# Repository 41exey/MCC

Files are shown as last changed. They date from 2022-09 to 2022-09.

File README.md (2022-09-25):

# Microclimate controller (MCC)







> Project based STM32F030K6T6

## Dependensies

- CMSIS

## Uses hardware

- TIM1 - sensor
- TIM3_CH3 PWM - backlight
- TIM14 - buttons
- TIM16 - time
- TIM17 - empty

- ADC1_IRQ - battery level

- Internal flash - storage settings

## Clone

> Clone this repo to your local machine using `git clone https://github.com/c1ewd/MCC`

## Features

> Device intended for measuring humidity and temperature. By deviation from specified range of temperature or humidity it send sound signal.
> Hardware design was making in Eagle CAD. Software was coding in IAR.
> Device is using digital humidity and temperature sensor AM2302. For sound signal using EFM-475. For graphical interface using Nokia 5110 display.

## Donations (Optional)

Liberapay (https://liberapay.com/c1ewd/donate)

## License

- **[Apache 2.0 license](http://www.apache.org/licenses/LICENSE-2.0)**
- Copyright © 2020 <a href="https://teleg.run/c1ewd" target="_blank">c1ewd</a>.

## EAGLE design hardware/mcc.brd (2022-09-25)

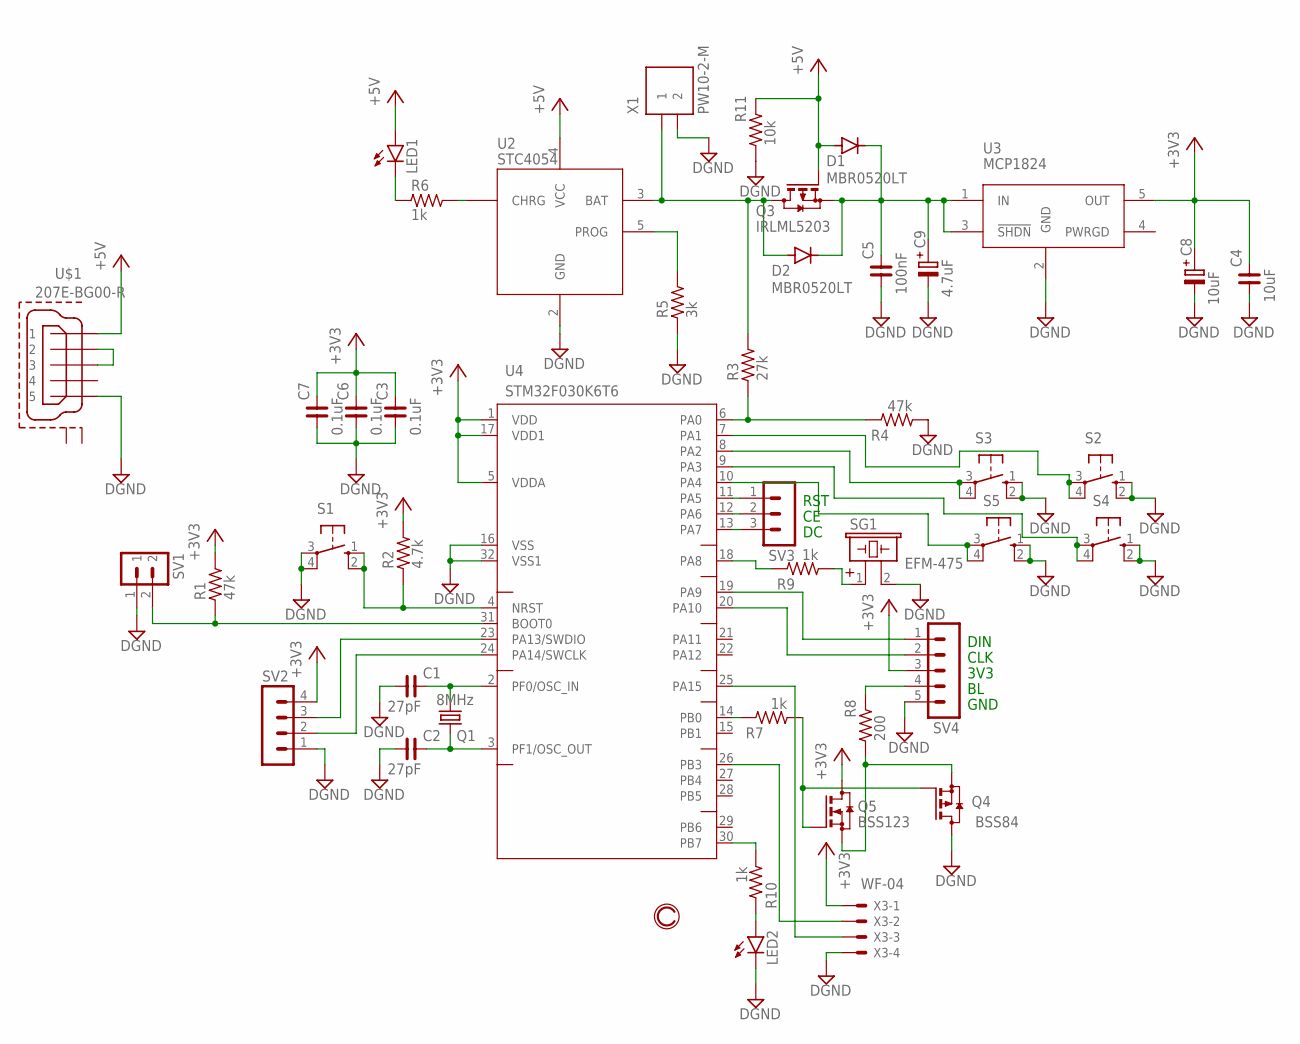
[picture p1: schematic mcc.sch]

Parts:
C1, C2: 27pF; C0805
C3, C6, C7: 0.1uF; C0805
C4: 10uF; C1206
C5: 100nF; C0805
C8: 10uF; SV-C
C9: 4.7uF; SV-C
D1, D2: MBR0520LT; SOD123
LED1, LED2: LEDSML0805; SML0805
Q1: 8MHz; HC49UP
Q3: IRLML5203; SOT23
Q4: BSS84; SOT23
Q5: BSS123; SOT23
R1, R4: 47k; R0805
R2: 4.7k; R0805
R3: 27k; R0805
R5: 3k; R0805
R6, R7, R9, R10: 1k; R0805
R8: 200; R0805
R11: 10k; R0805
S1, S2, S3, S4, S5: 10-XX; B3F-10XX
SG1: EFM-475; EFM-472
SV1: MA02-1
SV2: MA04-1
SV3: MA03-1
SV4: MA05-1
U2: STC4054; SOT23-5L
U3: MCP1824; SOT23-5L
U4: STM32F030K6T6; LQFP-32
U$1: 207E-BG00-R
X1: PW10-2-M; MKS1852-6-0-202
X3: WF-04; 22-23-2041

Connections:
+3V3: C3.2, C4.2, C6.2, C7.2, C8.+, Q5.3 (D), R1.2, R2.2, SV2.4, SV4.3, U3.5 (OUT), U4.1 (VDD), U4.5 (VDDA), U4.17 (VDD1), X3.1
BAT: D2.A, Q3.3 (D), R3.2, U2.3 (BAT), X1.1
BL: R7.2, U4.14 (PB0)
BOOT0: R1.1, SV1.2, U4.31 (BOOT0)
BUZZER: R9.2, U4.18 (PA8)
CE: SV3.2, U4.12 (PA6)
CHRG: R6.2, U2.1 (CHRG)
CLK: SV4.2, U4.20 (PA10)
DATA: U4.26 (PB3), X3.2
DC: SV3.3, U4.13 (PA7)
DGND: C1.1, C2.1, C3.1, C4.1, C5.1, C6.1, C7.1, C8.-, C9.-, LED2.C, Q4.3 (D), R4.1, R5.1, R11.1, S1.3, S1.4 (P1), S2.1 (S), S2.2 (S1), S3.1 (S), S3.2 (S1), S4.1 (S), S4.2 (S1), S5.1 (S), S5.2 (S1), SG1.2, SV1.1, SV2.1, SV4.5, U2.2 (GND), U3.2 (GND), U4.16 (VSS), U4.32 (VSS1), U$1.P$5 (5), X1.2, X3.4
DIN: SV4.1, U4.19 (PA9)
DIV_BAT: R3.1, R4.2, U4.6 (PA0)
LED2: R10.1, U4.30 (PB7)
unnamed: C5.2, C9.+, D1.C, D2.C, Q3.2 (S), U3.1 (IN), U3.3 (!SHDN)
unnamed: U$1.P$2 (2), U$1.P$3 (3)
unnamed: R8.2, SV4.4
unnamed: U4.25 (PA15), X3.3
NRST: R2.1, S1.1 (S), S1.2 (S1), U4.4 (NRST)
PF0-OSC_IN: C1.2, Q1.1, U4.2 (PF0/OSC_IN)
PF1-OSC_OUT: C2.2, Q1.2, U4.3 (PF1/OSC_OUT)
PROG: R5.2, U2.5 (PROG)
RST: SV3.1, U4.11 (PA5)
R_BL: Q4.1 (G), Q5.1 (G), R7.1
R_BUZZER: R9.1, SG1.1
R_CHRG: LED1.C, R6.1
R_LED2: LED2.A, R10.2
S2: S2.3, S2.4 (P1), U4.7 (PA1)
S3: S3.3, S3.4 (P1), U4.8 (PA2)
S4: S4.3, S4.4 (P1), U4.9 (PA3)
S5: S5.3, S5.4 (P1), U4.10 (PA4)
SWCLK: SV2.2, U4.24 (PA14/SWCLK)
SWDIO: SV2.3, U4.23 (PA13/SWDIO)
VCC: D1.A, LED1.A, Q3.1 (G), R11.2, U2.4 (VCC), U$1.P$1 (1)
Е_BL: Q4.2 (S), Q5.2 (S), R8.1

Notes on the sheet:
RST
DIN
CLK
3V3
GND

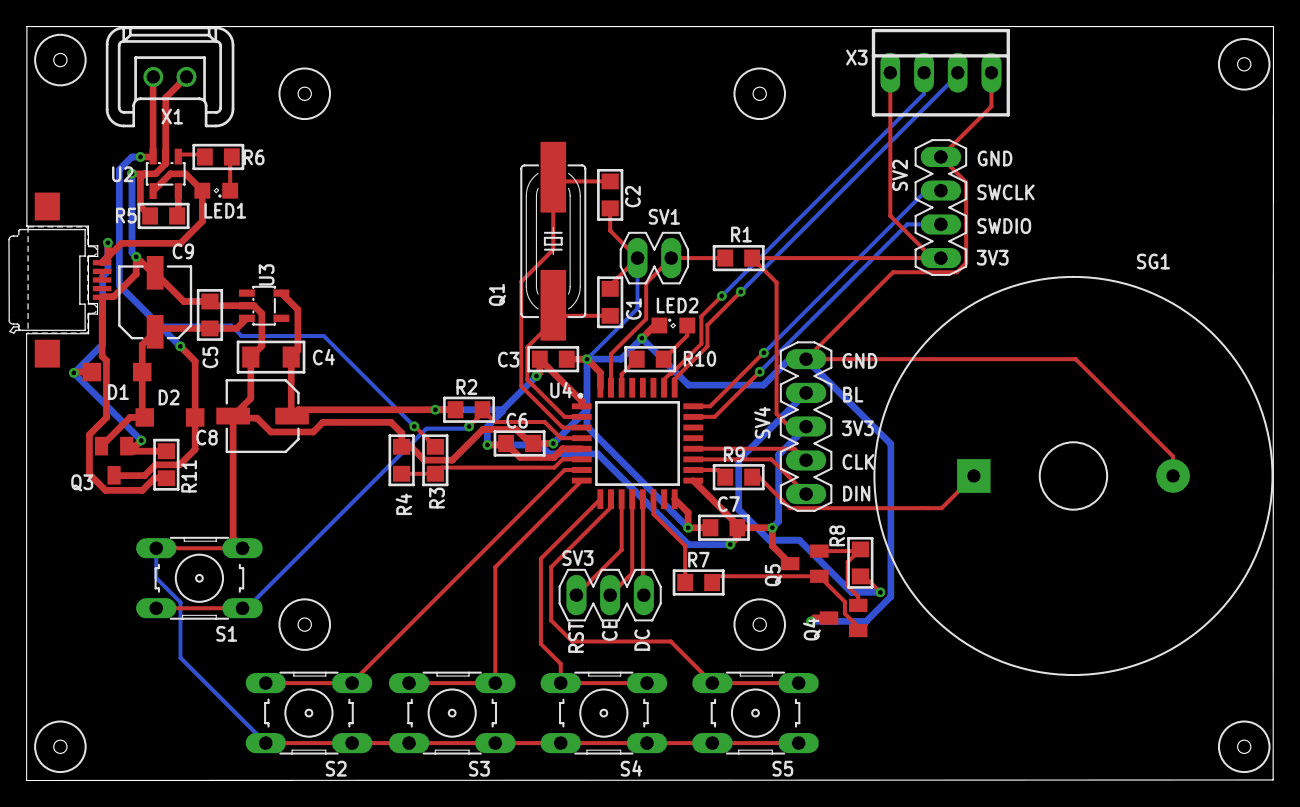
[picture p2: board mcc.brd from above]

Board: 2 copper layers, 94.0 x 56.8 mm, 44 parts (0 on the bottom side), 35 nets.

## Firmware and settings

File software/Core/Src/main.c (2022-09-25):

/*
 * Copyright 2020 c1ewd
 *
 * Licensed under the Apache License, Version 2.0 (the "License");
 * you may not use this file except in compliance with the License.
 * You may obtain a copy of the License at
 *
 *      http://www.apache.org/licenses/LICENSE-2.0
 *
 * Unless required by applicable law or agreed to in writing, software
 * distributed under the License is distributed on an "AS IS" BASIS,
 * WITHOUT WARRANTIES OR CONDITIONS OF ANY KIND, either express or implied.
 * See the License for the specific language governing permissions and
 * limitations under the License.
 */

#include "main.h"
#include "define.h"

#include "am2302.h"
#include "buttons.h"
#include "backlight.h"
#include "flash.h"
#include "string.h"
#include "sound.h"

/**
Test function indicates that MCU works
*/
void TIM17_IRQHandler(void)
{
//  LED_PORT->ODR ^= LED_ODR;
//  BUZZER_PORT->ODR ^= BUZZER_ODR;
    
  TIM17->SR &=~ TIM_SR_UIF;
}

/**
 * Program delay in milliseconds
 * @param ms delay in milliseconds
 */
void delay(uint32_t ms) {
  for(int i = 0; i < ms; i ++)
  {//48000000
    for(int j = 0; j < 48000; j ++)
    {
      __NOP();
    }
  }
}

int main(void)
{

  RCC->AHBENR |= RCC_AHBENR_GPIOBEN;
  // led
  GPIOB->MODER |= GPIO_MODER_MODER7_0;
  GPIOB->OTYPER &= ~GPIO_OTYPER_OT_7;
  GPIOB->OSPEEDR |= GPIO_OSPEEDER_OSPEEDR7;
  GPIOB->PUPDR |= GPIO_PUPDR_PUPDR7_0;
  
  RCC->AHBENR |= RCC_AHBENR_GPIOAEN;
  // Display
  // PA5
  GPIOA->MODER |= GPIO_MODER_MODER5_0;
  GPIOA->OTYPER &= ~GPIO_OTYPER_OT_5;
  GPIOA->OSPEEDR |= GPIO_OSPEEDER_OSPEEDR5;
  GPIOA->PUPDR &= ~GPIO_PUPDR_PUPDR5;
  // PA6
  GPIOA->MODER |= GPIO_MODER_MODER6_0;
  GPIOA->OTYPER &= ~GPIO_OTYPER_OT_6;
  GPIOA->OSPEEDR |= GPIO_OSPEEDER_OSPEEDR6;
  GPIOA->PUPDR &= ~GPIO_PUPDR_PUPDR6;   
  // PA7
  GPIOA->MODER |= GPIO_MODER_MODER7_0;
  GPIOA->OTYPER &= ~GPIO_OTYPER_OT_7;
  GPIOA->OSPEEDR |= GPIO_OSPEEDER_OSPEEDR7;
  GPIOA->PUPDR &= ~GPIO_PUPDR_PUPDR7;     
  // PA9
  GPIOA->MODER |= GPIO_MODER_MODER9_0;
  GPIOA->OTYPER &= ~GPIO_OTYPER_OT_9;
  GPIOA->OSPEEDR |= GPIO_OSPEEDER_OSPEEDR9;
  GPIOA->PUPDR &= ~GPIO_PUPDR_PUPDR9;
  // PA10
  GPIOA->MODER |= GPIO_MODER_MODER10_0;
  GPIOA->OTYPER &= ~GPIO_OTYPER_OT_10;
  GPIOA->OSPEEDR |= GPIO_OSPEEDER_OSPEEDR10;
  GPIOA->PUPDR &= ~GPIO_PUPDR_PUPDR10; 

  // PWM Display
  // TIM3_CH3
  // Configure PB0 for BL of LCD
//  GPIOB->MODER &= ~GPIO_MODER_MODER0;
  GPIOB->MODER |= GPIO_MODER_MODER0_1;
  GPIOB->OTYPER &= ~GPIO_OTYPER_OT_0;
  GPIOB->OSPEEDR |= GPIO_OSPEEDER_OSPEEDR0;
  GPIOB->PUPDR &= ~GPIO_PUPDR_PUPDR0;    
    
  // Enable PWM for LCD
  // Select AF1 on PB0 in AFRL for TIM3_CH3
  GPIOB->AFR[0] |= 0x01 << GPIO_AFRL_AFRL0_Pos;
  RCC->APB1ENR |= RCC_APB1ENR_TIM3EN;
  TIM3->PSC = 4800 - 1;
  TIM3->ARR = 100;
  TIM3->CCR3 = 100;
  TIM3->CCER |= TIM_CCER_CC3E;
  TIM3->BDTR |= TIM_BDTR_MOE;
  TIM3->CCMR2 = TIM_CCMR2_OC3M_2 | TIM_CCMR2_OC3M_1 | TIM_CCMR2_OC3PE;
  NVIC_SetPriority(TIM3_IRQn, 1);
  NVIC_EnableIRQ(TIM3_IRQn);
  TIM3->DIER = TIM_DIER_UIE;    
  TIM3->EGR |= TIM_EGR_UG;
    
  // time
  RCC->APB2ENR |= RCC_APB2ENR_TIM16EN;
  TIM16->PSC = 48000 - 1;
  TIM16->ARR = 500 - 1; // one per second, tested
  TIM16->CNT = 0;
  NVIC_SetPriority(TIM16_IRQn, 1);
  NVIC_EnableIRQ(TIM16_IRQn);
  TIM16->DIER = TIM_DIER_UIE;    
  TIM16->CR1 |= TIM_CR1_CEN | TIM_CR1_ARPE;
  
  // buzzer
  GPIOA->MODER |= GPIO_MODER_MODER8_0;
  GPIOA->OTYPER &= ~GPIO_OTYPER_OT_8;
  GPIOA->OSPEEDR |= GPIO_OSPEEDER_OSPEEDR8;
  GPIOA->PUPDR &= ~GPIO_PUPDR_PUPDR8;
  
  // TIM for tests
  /*
  RCC->APB2ENR |= RCC_APB2ENR_TIM17EN;
  TIM17->PSC = 48000 - 1;
  TIM17->ARR = 500;
  TIM17->CNT = 0;
  NVIC_SetPriority(TIM17_IRQn, 1);
  NVIC_EnableIRQ(TIM17_IRQn);
  TIM17->DIER = TIM_DIER_UIE;    
  TIM17->CR1 |= TIM_CR1_CEN | TIM_CR1_ARPE;
*/
  
  // PA0 ADC
  GPIOA->MODER |= GPIO_MODER_MODER0;
  // RCC of ADC
  RCC->APB2ENR |= RCC_APB2ENR_ADC1EN;
  RCC->CR2 |= RCC_CR2_HSI14ON;
  while((RCC->CR2 & RCC_CR2_HSI14RDY) == 0) {

  }

  ADC1->CFGR2 &= ~ADC_CFGR2_CKMODE;
  ADC1->CFGR2 |= ADC_CFGR2_CKMODE_1;
    
  ADC1->CFGR1 = 0;
    
  ADC1->CFGR1 |= ADC_CFGR1_CONT | ADC_CFGR1_SCANDIR;
  ADC1->CHSELR = ADC_CHSELR_CHSEL0;
  ADC1->SMPR |= ADC_SMPR_SMP_0 | ADC_SMPR_SMP_1 | ADC_SMPR_SMP_2;
  ADC1->IER = ADC_IER_EOCIE;
  NVIC_EnableIRQ(ADC1_COMP_IRQn);
  NVIC_SetPriority(ADC1_COMP_IRQn, 2);
    
  // Calibration
  // If enable
  if ((ADC1->CR & ADC_CR_ADEN) != 0) {
    ADC1->CR |= ADC_CR_ADDIS;
  }
  
  while((ADC1->CR & ADC_CR_ADEN) != 0) {

  }

  ADC1->CFGR1 &= ~ADC_CFGR1_DMAEN;
  ADC1->CR |= ADC_CR_ADCAL;
  while((ADC1->CR & ADC_CR_ADCAL) != 0) {
  }
    
  // ADC enable

  ADC1->CR |= ADC_CR_ADEN;
  while((ADC1->ISR & ADC_ISR_ADRDY) == 0) {
   
  }
    
  ADC1->CR |= ADC_CR_ADSTART;
  
  // AM2302
  // DATA pin is PB3
  GPIOB->MODER &= ~GPIO_MODER_MODER3;
  GPIOB->MODER |= GPIO_MODER_MODER3_0;
  GPIOB->OTYPER |= GPIO_OTYPER_OT_3;
  GPIOB->OSPEEDR |= GPIO_OSPEEDER_OSPEEDR3;
  GPIOB->PUPDR &= ~GPIO_PUPDR_PUPDR3;
    
  // AM2302 polling by TIM1
  RCC->APB2ENR |= RCC_APB2ENR_TIM1EN;
  // 240 / 48 000 000 = 1 / 200 000 = 0.000005 s = 0.005 ms = 5 us
  TIM1->PSC = 240 - 1;
  TIM1->ARR = 1;
  NVIC_SetPriority(TIM1_BRK_UP_TRG_COM_IRQn, 0);
  NVIC_EnableIRQ(TIM1_BRK_UP_TRG_COM_IRQn);
  TIM1->DIER = TIM_DIER_UIE;    
  TIM1->CR1 |= TIM_CR1_CEN | TIM_CR1_ARPE;
  TIM1->EGR |= TIM_EGR_UG;

  // Buttons
  // S2 - PA1
  // S3 - PA2
  // S4 - PA3
  // S5 - PA4
  // PA1
  GPIOA->MODER &= ~GPIO_MODER_MODER1; // Input mode
  GPIOA->OTYPER &= ~GPIO_OTYPER_OT_1; // Output push pull
  GPIOA->OSPEEDR |= GPIO_OSPEEDER_OSPEEDR1; // High speed
  GPIOA->PUPDR &= ~GPIO_PUPDR_PUPDR1;
  GPIOA->PUPDR |= GPIO_PUPDR_PUPDR1_0; // Pull-up
  // PA2
  GPIOA->MODER &= ~GPIO_MODER_MODER2; // Input mode
  GPIOA->OTYPER &= ~GPIO_OTYPER_OT_2; // Output push pull
  GPIOA->OSPEEDR |= GPIO_OSPEEDER_OSPEEDR2; // High speed
  GPIOA->PUPDR &= ~GPIO_PUPDR_PUPDR2;
  GPIOA->PUPDR |= GPIO_PUPDR_PUPDR2_0; // Pull-up    
  // PA3
  GPIOA->MODER &= ~GPIO_MODER_MODER3; // Input mode
  GPIOA->OTYPER &= ~GPIO_OTYPER_OT_3; // Output push pull
  GPIOA->OSPEEDR |= GPIO_OSPEEDER_OSPEEDR3; // High speed
  GPIOA->PUPDR &= ~GPIO_PUPDR_PUPDR3;
  GPIOA->PUPDR |= GPIO_PUPDR_PUPDR3_0; // Pull-up
  // PA4
  GPIOA->MODER &= ~GPIO_MODER_MODER4; // Input mode
  GPIOA->OTYPER &= ~GPIO_OTYPER_OT_4; // Output push pull
  GPIOA->OSPEEDR |= GPIO_OSPEEDER_OSPEEDR4; // High speed
  GPIOA->PUPDR &= ~GPIO_PUPDR_PUPDR4;
  GPIOA->PUPDR |= GPIO_PUPDR_PUPDR4_0; // Pull-up
    
  // Buttons polling by TIM14
  RCC->APB1ENR |= RCC_APB1ENR_TIM14EN;
  TIM14->PSC = 480 - 1;
  TIM14->ARR = 50;
  TIM14->CNT = 0;
  NVIC_SetPriority(TIM14_IRQn, 1);
  NVIC_EnableIRQ(TIM14_IRQn);
  TIM14->DIER = TIM_DIER_UIE;    
  TIM14->CR1 |= TIM_CR1_CEN | TIM_CR1_ARPE;
  
  lcd8544_init();
  lcd8544_clear();
  lcd8544_refresh(); 
  lcd8544_power_down();
  
  soundDelay = 10;
  
//  flashFirst();
  
  flashRead((unsigned char *)&settings, MEMORY_PAGE, sizeof(settings)); // page 28
//  memcpy((void *)&settingsBackup, (void *)&settings, sizeof(settings)); // wait for changes
  
  while(1) {

    sensorRead();
    show();
    delay(100);
    
  }
  
}

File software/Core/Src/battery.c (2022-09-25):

/*
 * Copyright 2020 c1ewd
 *
 * Licensed under the Apache License, Version 2.0 (the "License");
 * you may not use this file except in compliance with the License.
 * You may obtain a copy of the License at
 *
 *      http://www.apache.org/licenses/LICENSE-2.0
 *
 * Unless required by applicable law or agreed to in writing, software
 * distributed under the License is distributed on an "AS IS" BASIS,
 * WITHOUT WARRANTIES OR CONDITIONS OF ANY KIND, either express or implied.
 * See the License for the specific language governing permissions and
 * limitations under the License.
 */

#include "battery.h"

volatile unsigned char count = 0;
volatile bool batteryFlag = false;

#define MAX_AVERAGE    5

volatile unsigned int averageArray[MAX_AVERAGE] = {0};

/**
 * Interrupt for battery level calculatinon
 */
void ADC1_IRQHandler(void)
{
  
//  ADC1->DR

  if (ADC1->ISR & ADC_ISR_EOC) {            /* ADC1 EOC interrupt?                */
//    GPIOB->ODR ^= GPIO_ODR_7;
//    lcd8544_clear();
//    lcd8544_dec(ADC1->DR, 4, 3, 3, 0);
//    lcd8544_refresh();
    
    averageArray[count] = ADC1->DR;
    
    if (count < MAX_AVERAGE)
      count++;
    else {
      batteryFlag = true;
      count = 0;
    }
    
    ADC1->ISR |= ADC_ISR_EOC;
  }
    
//  ADC1->IER &= ~ADC_IER_EOCIE;
}

/**
 * Shaping display buffer with battery level
 */
void batteryShapping() {

  //lcd8544_rect(1, 0, 82, 5, 1);
  if (batteryFlag == 0)
    return;
  
  lcd8544_line(4, 0, 81, 0, 1);
  lcd8544_line(4, 5, 81, 5, 1);
  lcd8544_line(4, 0, 4, 5, 1);
  
  lcd8544_putpix(81, 1, 1);
  lcd8544_putpix(81, 4, 1);
  
  lcd8544_putpix(82, 2, 1);
  lcd8544_putpix(82, 3, 1);
  
//  ADC1->DR
  // R3 = 27k
  // R4 = 47k
  // max 4 V
  // min 3 V
  // 1 / 5 = 0.2
  // 3.2 = , 3.4 = , 3.6 = , 3.8 = , 4.0 = 
  // 12 bit ADC
  // 4 096
  
  // wait
  // 3.3 V + dropout
  // dropout is 200 mV
  // 3.5 V
  // 4 - 3.5 = 0.5
  // 0.5 / 5 = 0.1
  // 4.0 = 2.541,
  // 2.541 * 4096 / 3.3 = 3 153
  // 3.9V = 2.477V = 3 074ADC, 3.8V = 2.414V = 2 996ADC,
  // 3.7V = 2.35V = 2 916ADC, 3.6V = 2.286V = 2 837ADC, 3.5V = 2.223V = 2 759ADC
  // 
  
  unsigned int average = 0;
  for(int i = 0; i < MAX_AVERAGE; i++)
    average += averageArray[i];
  average /= MAX_AVERAGE;
  
  int division = 0;
  
  if (average >= 3153)
    division = 5;
  else if (average >= 3074)
    division = 4;
  else if (average >= 2996)
    division = 3;
  else if (average >= 2916)
    division = 2;
  else if (average >= 2837)
    division = 1;
  else
    division = 0;
  
  for(int i = 0; i < division; i++) {
    lcd8544_rect(6 + i * 15, 2, 19 + i * 15, 3, 1);
  }
  
  // checking iteration
  // 0:
  // 3 + 0 * 15 = 3
  // 18 + 0 * 15 = 18
  // 1:
  // 3 + 1 * 15 = 18
  // 18 + 1 * 15 = 33
  
  // 4:
  // 3 + 4 * 15 = 63
  // 16 + 4 * 15 = 76
  
  // 83 - 76 = 7
  // 7 / 2 = 3.5 | 4 - 3
 
/*  
  lcd8544_rect(4, 2, 18, 3, 1);
  lcd8544_rect(20, 2, 34, 3, 1);
  lcd8544_rect(36, 2, 50, 3, 1);
  lcd8544_rect(52, 2, 64, 3, 1);
  lcd8544_rect(66, 2, 81, 3, 1);
*/
//  lcd8544_refresh();
}

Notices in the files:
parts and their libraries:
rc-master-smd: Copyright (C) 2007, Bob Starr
